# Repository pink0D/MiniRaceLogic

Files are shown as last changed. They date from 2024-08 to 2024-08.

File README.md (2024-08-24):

# About
This toy project builds some kind of electronic start and finish lines to be used with 1:64 scale cars and tracks (a.k.a. Hot Wheels)

### Features:
- 433 mhz remote control 
- RF communication between start/finish lines
- car velocity and finish time indication
- dual mode logic: track mode (finish time only) and circuit mode (lap time and best time)
- false start trigger
- sound effects with passive buzzer
- auto power off

### Demo videos:

[Demo video 1 on YouTube](https://www.youtube.com/watch?v=u52nJqy7JgE)

video2 (https://www.youtube.com/watch?v=u52nJqy7JgE)

[Demo video 2 on YouTube](https://www.youtube.com/watch?v=M21zNXTgTHc)

video3 (https://www.youtube.com/watch?v=M21zNXTgTHc)

# Hardware

### Required components
- 2x RF-Nano, resistors, transistors, LEDs (including IR), photodiodes, pushbuttons, passive buzzers, batteries
- 4x8 RGB LED HAT (or similiar addressable LED strip / matrix), 433 mhz remote and receiver for start controller
- LCD1602 with I2C connection for finish controller

### Wiring diagram
Same both for start and finish controllers (the only difference is that LED matrix is connected to start, and LCD is connected to finish)

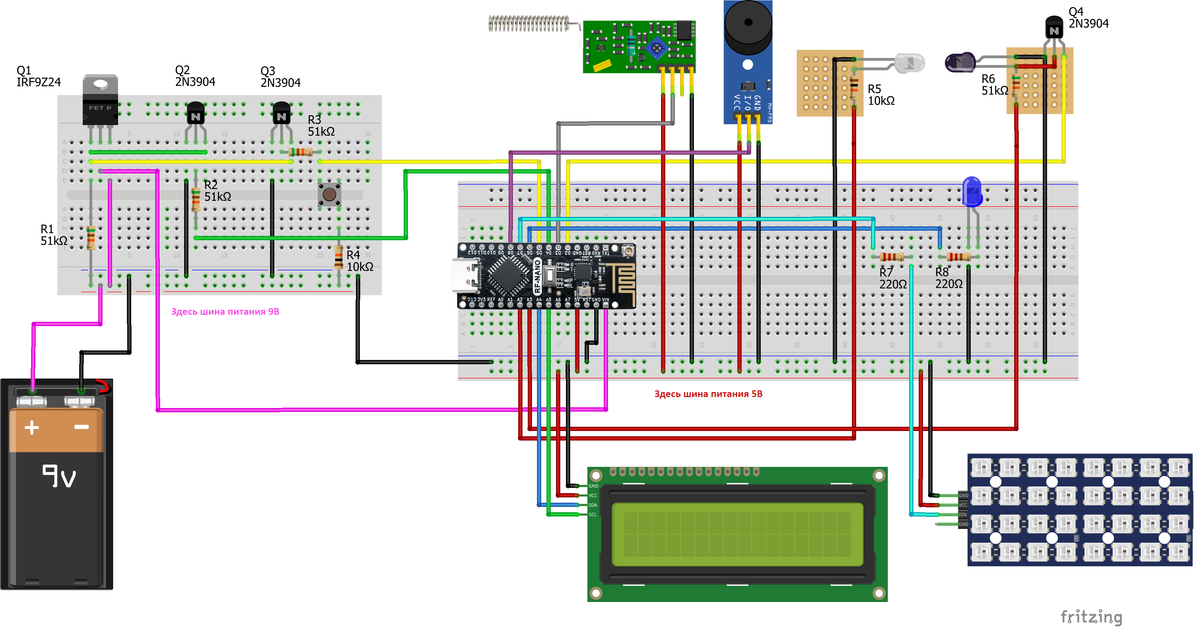
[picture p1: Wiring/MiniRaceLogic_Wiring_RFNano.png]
Wiring! Wiring


# Firmware
Arduino sketch is common both for start and finish.
Look at `#define` inside `Settings.h` before uploading and comment/uncomment `#define DEVICE_TYPE` line to load sketch to start or to finish controller

# Repo structure
- Arduino code (depends on [LCD_AIP31068_I2C_WCHAR](https://github.com/pink0D/LCD_AIP31068_I2C_WCHAR) library)
- STL files which can be used to 3D print shells. Autodesk Fusion source file is also available

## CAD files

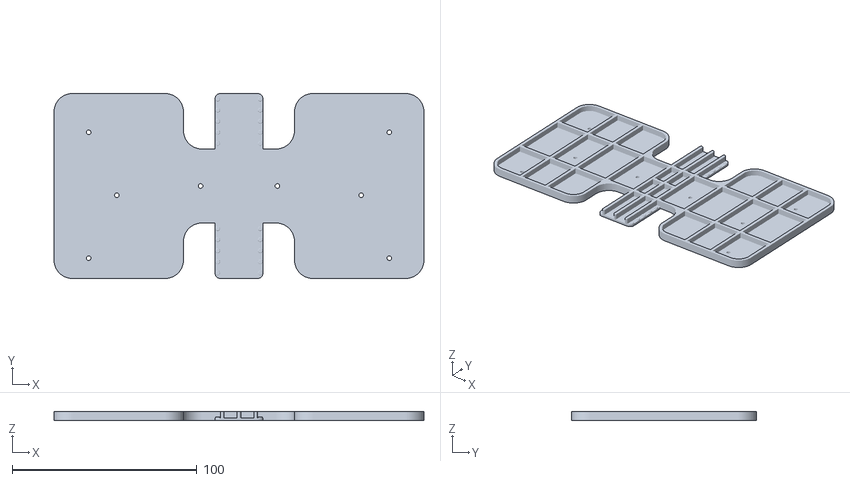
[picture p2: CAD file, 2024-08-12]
STL/TrackFixMain_2x_black.stl
200.0 x 100.0 x 5.00

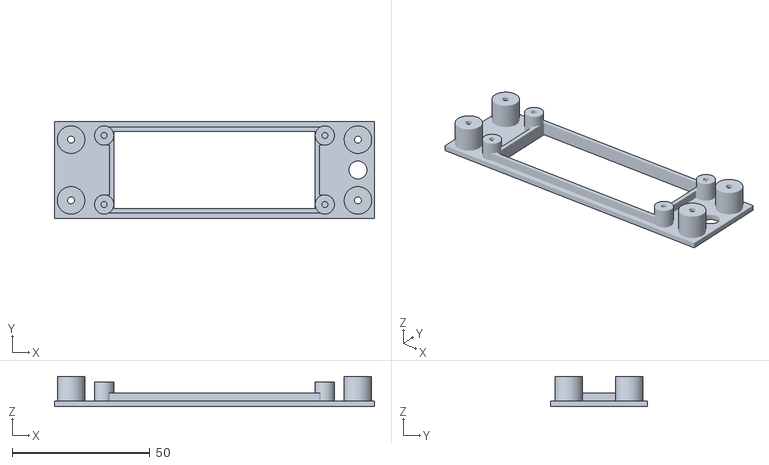
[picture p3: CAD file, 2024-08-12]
STL/LCDHolder_1x_black.stl
116.0 x 35.0 x 11.0

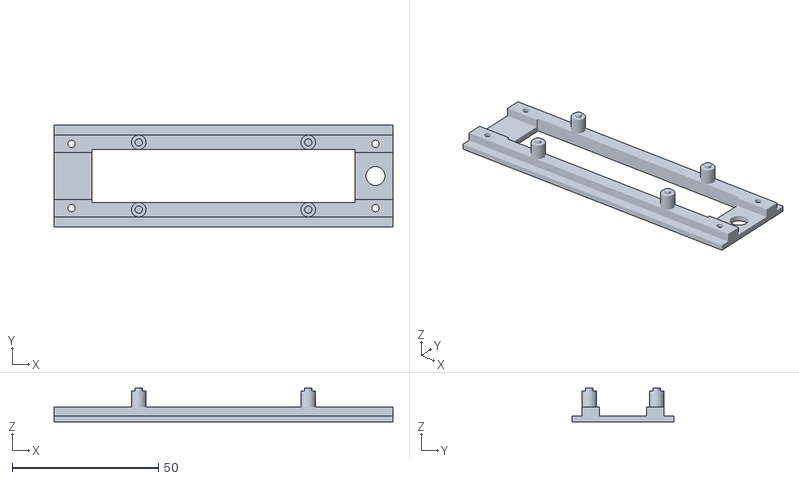
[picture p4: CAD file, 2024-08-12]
STL/RGBFix_1x_black.stl
116.0 x 35.0 x 11.5

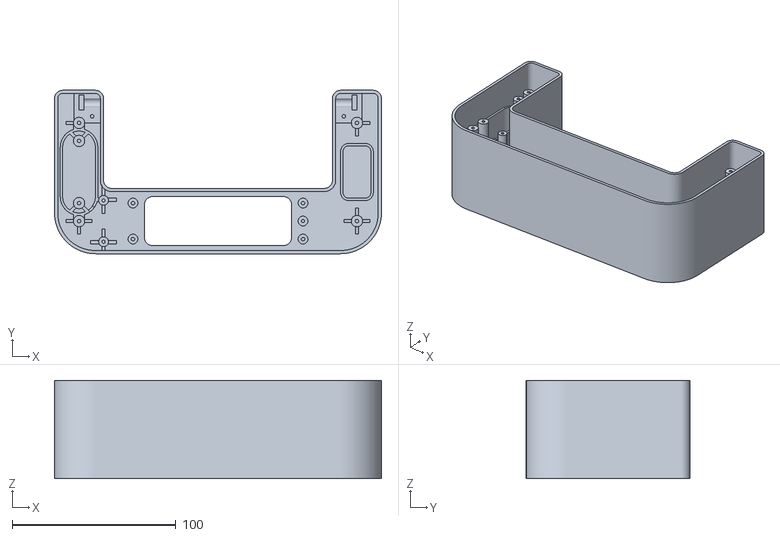
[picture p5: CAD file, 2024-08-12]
STL/ExtShell_2x_white.stl
200.0 x 100.0 x 60.0

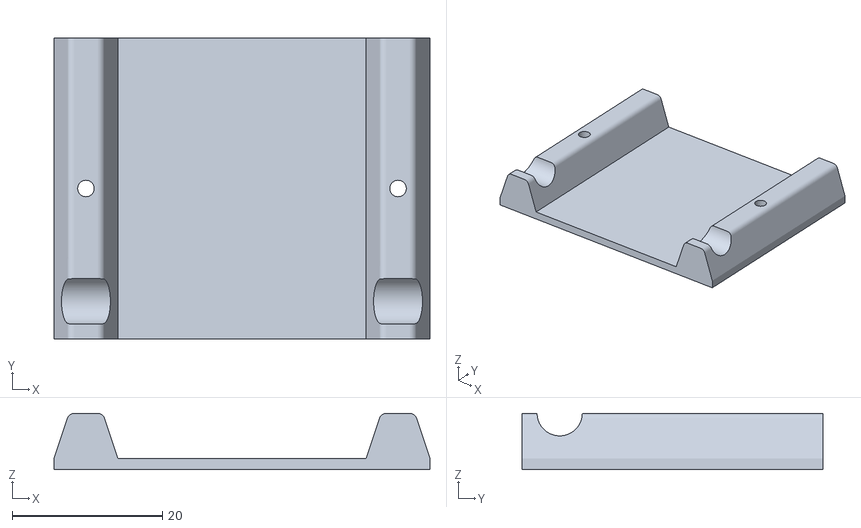
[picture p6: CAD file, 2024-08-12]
STL/TrackMid_2x_red.stl
50.0 x 40.0 x 7.50

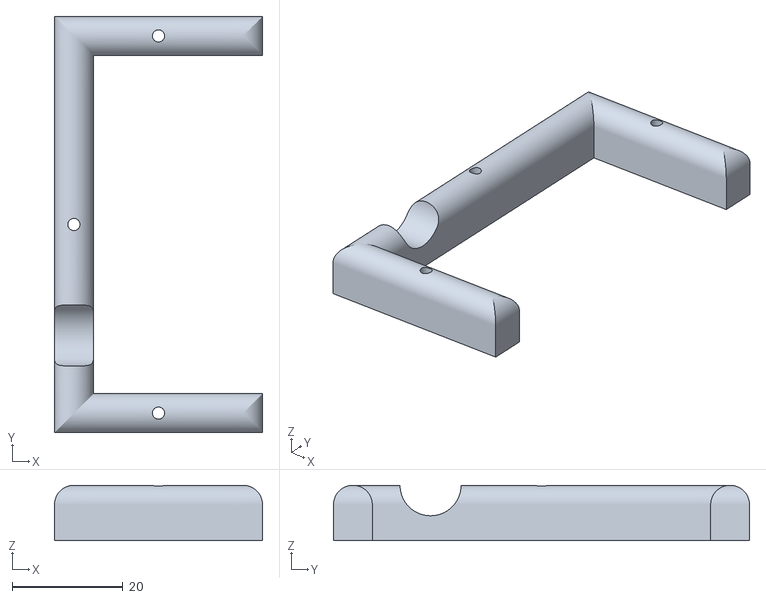
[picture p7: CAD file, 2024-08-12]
STL/TrackFixRight_2x_black.stl
37.5 x 75.0 x 10.0

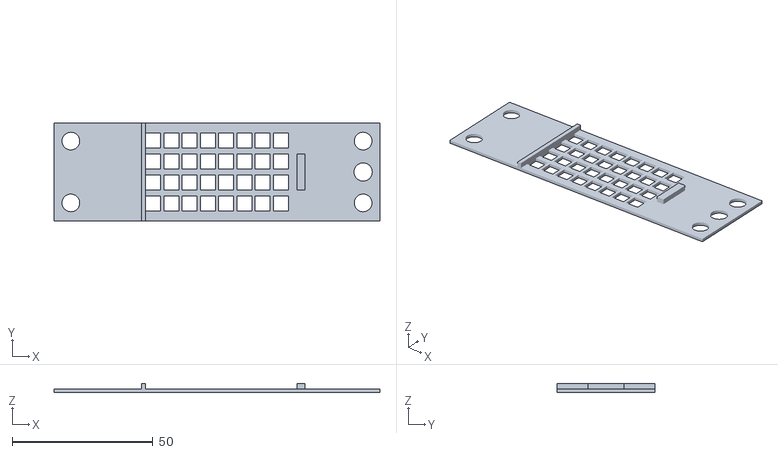
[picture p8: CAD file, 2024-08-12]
STL/RGBHolder_1x_black.stl
116.0 x 35.0 x 3.20

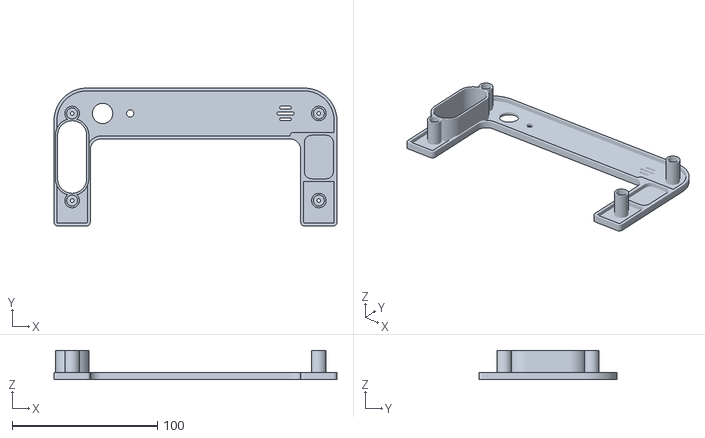
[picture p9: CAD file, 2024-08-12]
STL/ExtCover_2x_white.stl
195.0 x 95.0 x 20.0

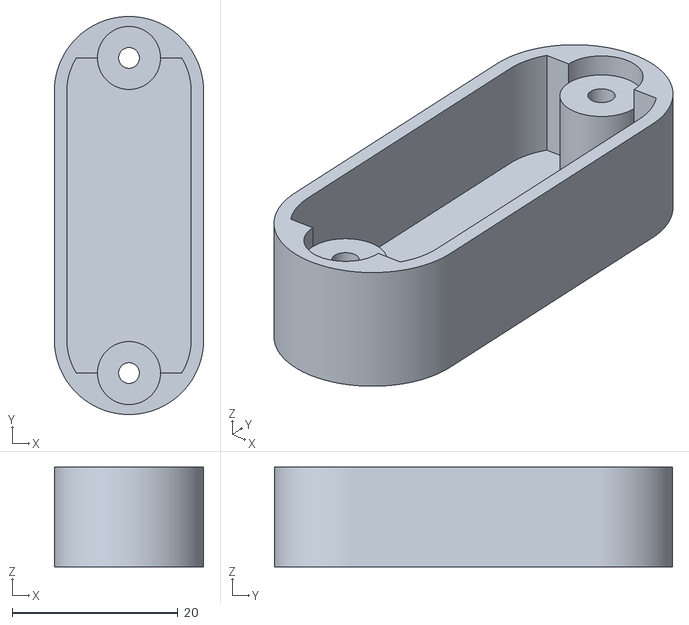
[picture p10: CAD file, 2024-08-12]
STL/BatCover_2x_white.stl
18.0 x 48.0 x 12.0

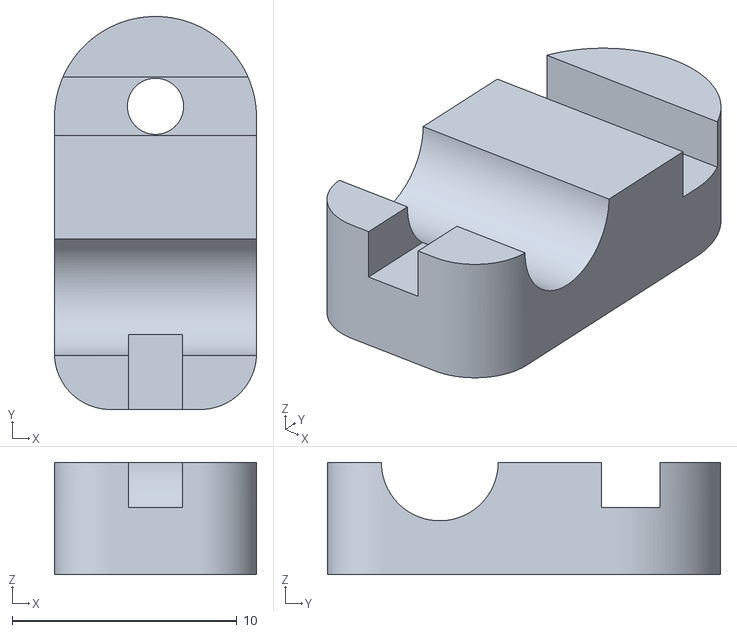
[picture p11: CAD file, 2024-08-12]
STL/LEDFix_4x_black.stl
9.00 x 17.5 x 5.00

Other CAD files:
STL/TrackFixLeft_2x_black.stl
STL/MiniRaceLogic_shell.f3d

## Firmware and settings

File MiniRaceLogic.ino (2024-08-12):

#include <RCSwitch.h>
#include <avr/wdt.h>

#include <LCD_AIP31068_I2C_WCHAR.h>
#include <LCD_CharMap_RUS.h>

#include "Settings.h"
#include "PowerControl.h"
#include "LedPanel.h"
#include "LedPatterns.h"
#include "TonePlayer.h"
#include "SoundTones.h"
#include "LCD.h"
#include "Radio.h"
#include "Optic.h"
#include "RaceLogic.h"

#include "LedPatterns_PROGMEM.h"
#include "SoundTones_PROGMEM.h"

RCSwitch rcswitch;

void setup() {
  s_TonePlayer.begin();

  Serial.begin(9600);

  if (DEVICE_TYPE == DEVICE_TYPE_FINISH) {
    s_LCD.init();
    s_LCD.clear();   
  }
  
  if (DEVICE_TYPE == DEVICE_TYPE_START) {
    rcswitch.enableReceive(digitalPinToInterrupt(RC_PIN)); 
    s_LedPanel.begin();
    s_LedPanel.stop();
  }

  s_PowerControl.on();
  
  if (DEVICE_TYPE == DEVICE_TYPE_START) {
    s_LedPanel.start_play_pgm_patterns(led_welcome,led_welcome_size);
  }

  if (DEVICE_TYPE == DEVICE_TYPE_FINISH) {
    s_LCD.setCursor(5,0);
    s_LCD.print("ПРИВЕТ");
  }

  s_Radio.begin();
  s_Radio.prepare_listen();

  s_Optic.begin();

  if (DEVICE_TYPE == DEVICE_TYPE_START)
    s_pRaceLogic = new RaceLogicStart();
  if (DEVICE_TYPE == DEVICE_TYPE_FINISH)
    s_pRaceLogic = new RaceLogicFinish();

  if (WATCHDOG_ENABLE == 1)
    wdt_enable(WDTO_8S);
}

void loop() {
  wdt_reset();

  if (DEVICE_TYPE == DEVICE_TYPE_START) {
     rcswicth_loop();   
     s_LedPanel.loop();
  }

  s_Radio.loop();
  s_PowerControl.loop();
  s_TonePlayer.loop(); 

  s_pRaceLogic->loop(); 
}

void rcswicth_loop() {
  if (rcswitch.available()) {
    unsigned long hex = rcswitch.getReceivedValue();

    s_pRaceLogic->rc_command(hex);
  
    rcswitch.resetAvailable();
    s_PowerControl.timer_reset(); // reset auto off timer after RC command
  }
}

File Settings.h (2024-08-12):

#ifndef _SETTINGS_H_
#define _SETTINGS_H_

#include <Arduino.h>

#define WATCHDOG_ENABLE 0   // WARNING! works only with optiboot (new bootloader). old bootloader can go into bootloop

#define DEVICE_TYPE_START  0
#define DEVICE_TYPE_FINISH 1

#define DEVICE_TYPE DEVICE_TYPE_START 
//#define DEVICE_TYPE DEVICE_TYPE_FINISH

#define CAR_LENGTH_MM 70.0 // car length in mm (type must be double!)
#define CAR_VELOCITY_SCALE 64.0 // velocity multiplier for 1:64 scale cars (type must be double!)

#define RACE_DEFAULT_TIMEOUT 5000 // timeout for system status reset (after finish / false start)
#define RACE_START_FINISH_TIMEOUT 30000 // timeout for race status reset (in track mode)
#define RACE_LAP_TIMEOUT  60000 // race timeout (in lap mode)
#define RACE_LAP_MINIMUM  2000 // min lap time (in lap mode)

#define POWER_ON_TIMEOUT 500 // ms to wait for button power on
#define POWER_OFF_TIMEOUT 1000 // ms to wait for button power off
#define POWER_IDLE_TIMEOUT 300000 // ms for auto power off

#define POWER_CTL_PIN 4
#define POWER_BTN_PIN 5
#define POWER_LED_PIN 6

#define RC_PIN 3 

#define LED_SIGNAL_PIN   7

#define LCD_ADDRESS 0x7c>>1
#define LCD_ROWS 2
#define LCD_COLUMNS 16

#define BUZZER_PIN   8
#define BUZZER_OFF_VALUE HIGH // some buzzers are low-level triggered, so HIGH value turns VCC off

#define OPTIC_SIGNAL_PIN 2
#define OPTIC_SENSOR_POWER_PIN A3
#define OPTIC_LED_POWER_PIN A2

#define RF_CE_PIN 10
#define RF_CSN_PIN 9
#define RF_CHANNEL 27
#define RF_DATARATE RF24_1MBPS
#define RF_PALEVEL RF24_PA_MAX

const byte RF_ADDRESS_START[6] = "MRL2S";
const byte RF_ADDRESS_FINISH[6] = "MRL2F";

#define RC_TIMEOUT 1000

#define RC1_BUTTON1 0x0F7A88
#define RC1_BUTTON2 0x0F7A84
#define RC1_BUTTON3 0x0F7A82
#define RC1_BUTTON4 0x0F7A81

#define RC2_BUTTON1 0x8B2E88
#define RC2_BUTTON2 0x8B2E84
#define RC2_BUTTON3 0x8B2E82
#define RC2_BUTTON4 0x8B2E81

#endif

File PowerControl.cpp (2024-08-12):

#include "Settings.h"
#include "PowerControl.h"
#include "TonePlayer.h"
#include "SoundTones.h"

static PowerControl s_PowerControl;

void PowerControl::on() {
  delay(POWER_ON_TIMEOUT); // delay for POWER ON button pressed
  pinMode(POWER_CTL_PIN, OUTPUT);
  digitalWrite(POWER_CTL_PIN, HIGH);

  pinMode(POWER_LED_PIN, OUTPUT);
  digitalWrite(POWER_LED_PIN, HIGH);

  timer_reset();

  s_TonePlayer.start_play_pgm_tones(tone_power_on,tone_power_on_size);
}

void PowerControl::loop() {
  if (millis() < 5000)
    return;
    
  // power off button
  if (digitalRead(POWER_BTN_PIN) == HIGH) {
    delay(POWER_OFF_TIMEOUT); // check for button is still pressed after timeout
    if (digitalRead(POWER_BTN_PIN) == HIGH)
      off();
  }

  //auto power off
  if ( (time_auto_power_off > 0) && (millis() > time_auto_power_off) )
     off();
}

void PowerControl::off() {
  s_TonePlayer.start_play_pgm_tones_sync(tone_power_off,tone_power_off_size);
  digitalWrite(POWER_CTL_PIN, LOW);
  time_auto_power_off = 0; 
}

void PowerControl::timer_reset() {
  time_auto_power_off = millis() + POWER_IDLE_TIMEOUT; 
}
